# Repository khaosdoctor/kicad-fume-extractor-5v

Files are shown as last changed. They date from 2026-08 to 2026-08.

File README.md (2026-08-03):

# Fume Extractor 5V

KiCad project for a small, battery-powered fume extractor: a 9V battery feeds an
L7805 linear regulator to drive a 5V fan through a BC337 transistor, with a
potentiometer for speed control, a trimmer for calibration, a power switch and
an LED indicator.

This is my first electronics project, so it's a work in progress. Expect
multiple revisions as the design gets refined.

## PCB preview

| Top | Bottom |
|-----|---|
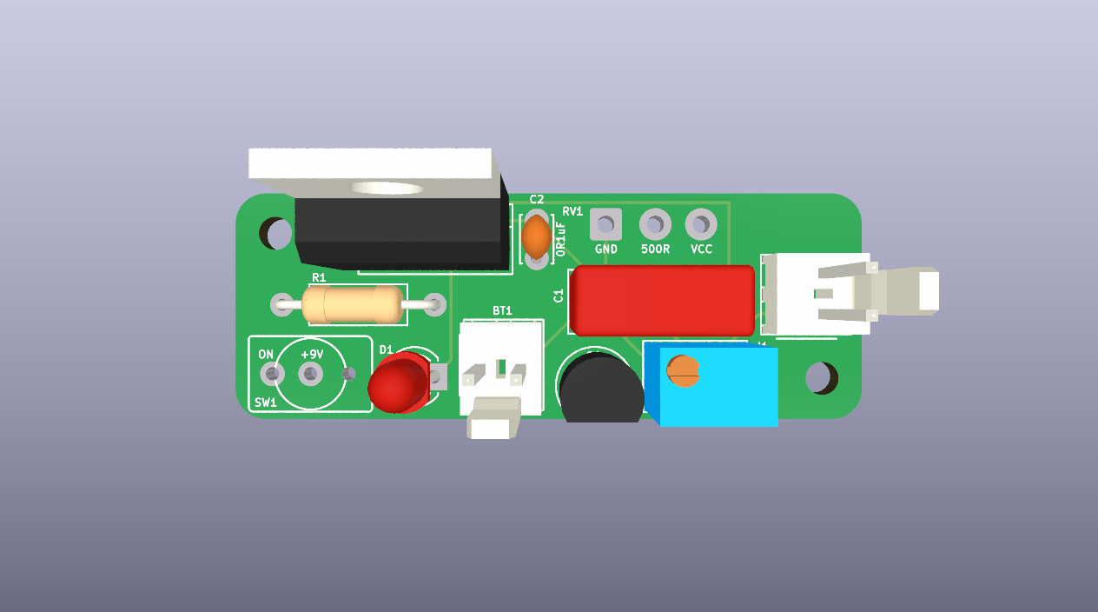
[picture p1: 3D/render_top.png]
PCB top view
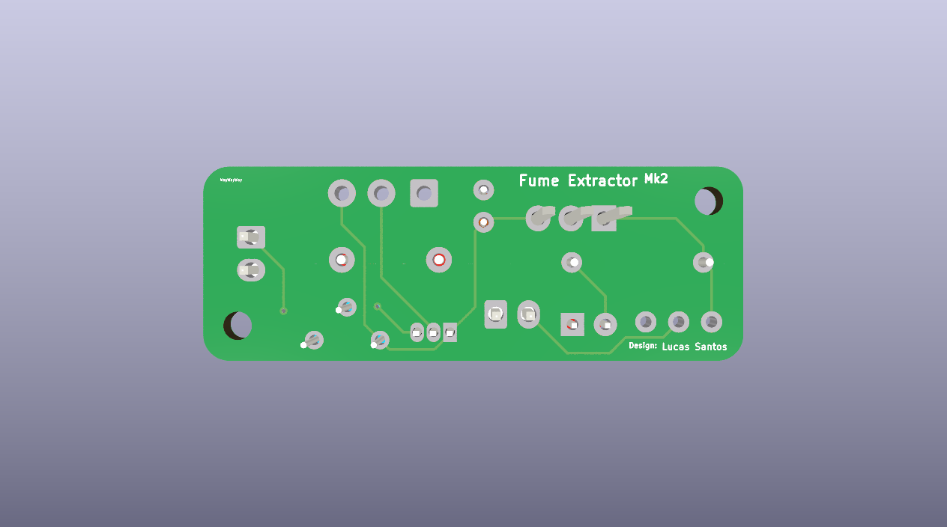
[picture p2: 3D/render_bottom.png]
PCB bottom view
|  |  |

## Hardware overview

Interactive BOM: [khaosdoctor.github.io/kicad-fume-extractor-5v/bom/ibom.html](https://khaosdoctor.github.io/kicad-fume-extractor-5v/bom/ibom.html)

| Ref  | Part | Function |
|---|---|---|
| BT1  | 9V battery cell | Power source |
| U1 | L7805ACV | 5V linear regulator |
| Q1 | BC337 | Fan drive transistor |
| J1 | 2-pin connector | Fan output |
| RV1  | 500R potentiometer | Fan speed control |
| RV2  | 1K trimmer | Calibration |
| R1 | 350R resistor | Bias/current limiting |
| C1/C2| Capacitors | Regulator input/output filtering  |
| D1 | LED | Power indicator |
| SW1  | SPST switch | Power on/off |

The board is a 2-layer PCB designed in KiCad 10.

## Generating manufacturing files with KiBot

This project uses [KiBot](https://github.com/INTI-CMNB/KiBot) to generate
gerbers, drill files, pick & place, BOM, documentation and 3D outputs
straight from the KiCad source files, via `kibot.yaml`.

### Outputs produced

| Group | Outputs | Directory |
|---|---|---|
| `fabrication` | Gerbers, Excellon drill files | `Manufacturing/Gerbers` |
| `assembly` | Pick & place position file, BOM (CSV) | `Manufacturing/Assembly`|
| `documentation` | Schematic PDF, PCB PDF, interactive HTML BOM | `Documentation`, `bom`  |
| `3d` | STEP model, top/bottom 3D renders | `3D` |

A zipped bundle of gerbers + drill files ready to send to a fab house is also
produced under `Manufacturing/manufacturing_zip.zip`. A JLCPCB-specific BOM
(`bom_jlcpcb`) filtered to parts with an LCSC part number is available but not
run by default.

### Running locally

Install KiCad (10.x) and KiBot, then from the repository root run:

```bash
pip install kibot
kibot -e "fume Extractor.kicad_sch" -b "fume Extractor.kicad_pcb"
```

To generate a single group or output, pass its name as a target, e.g.:

```bash
kibot -e "fume Extractor.kicad_sch" -b "fume Extractor.kicad_pcb" fabrication
```

### Running with Docker

No local KiCad/KiBot install is required if you have Docker:

```bash
docker run --rm -v "$(pwd)":/mnt ghcr.io/inti-cmnb/kicad10_auto_full:latest \
  kibot -e "fume Extractor.kicad_sch" -b "fume Extractor.kicad_pcb"
```

### Running in CI

The [`kibot.yml`](.github/workflows/kibot.yml) workflow runs KiBot on every
push and pull request and uploads the generated files as a build artifact.
On pushes to `main` it also commits the refreshed `bom/ibom.html`,
`3D/render_top.png` and `3D/render_bottom.png` back to the repo, which is
what keeps the PCB preview and interactive BOM link above up to date.

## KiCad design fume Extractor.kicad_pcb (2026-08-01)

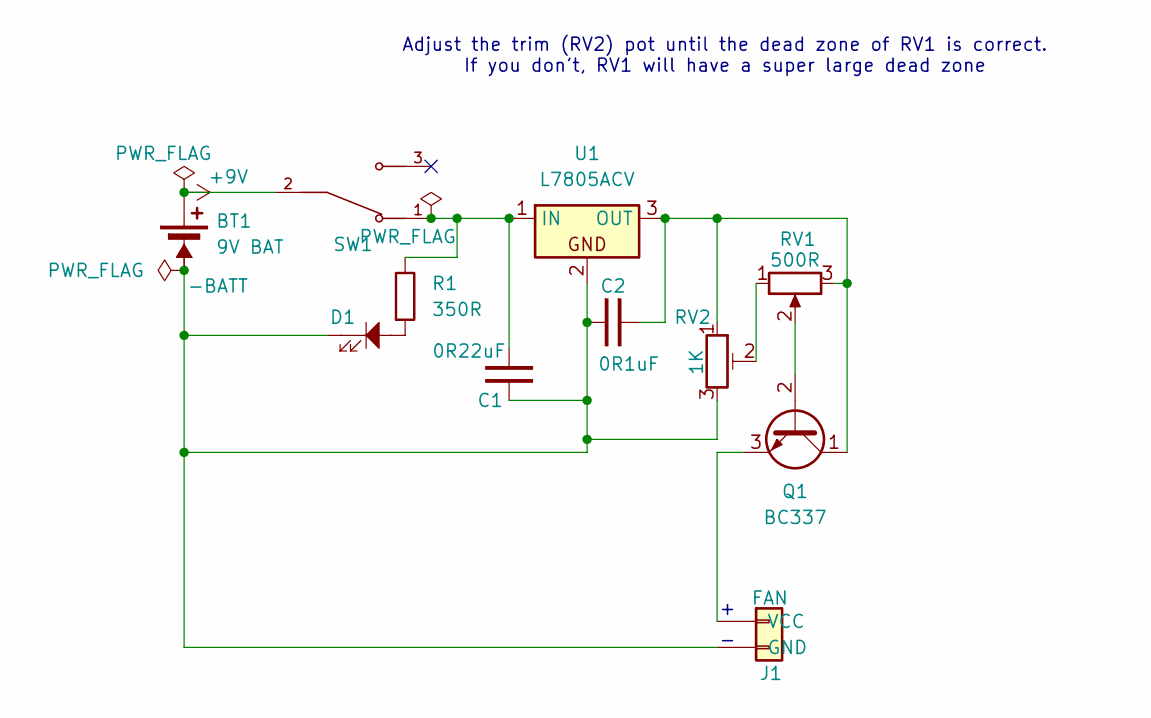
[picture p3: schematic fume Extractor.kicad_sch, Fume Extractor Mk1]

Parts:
BT1: 9V BAT; Molex_KK-254_AE-6410-02A_1x02_P2.54mm_Vertical
C1: 0R22uF; C_Rect_L10.0mm_W4.0mm_P7.50mm_MKS4
C2: 0R1uF; C_Disc_D3.0mm_W2.0mm_P2.50mm
D1: LED_3mm; LED_D3.0mm
J1: FAN; Molex_KK-254_AE-6410-02A_1x02_P2.54mm_Vertical
Q1: BC337; TO-92_Inline
R1: 350R; R_Axial_DIN0207_L6.3mm_D2.5mm_P10.16mm_Horizontal
RV1: 500R; SolderWire-0.5sqmm_1x03_P4.6mm_D0.9mm_OD2.1mm
RV2: 1K; Potentiometer_Bourns_3266W_Vertical
SW1: SW_SPST; Switch_Toggle_SPDT_SubMini; PARTREV E
U1: L7805ACV; TO-220-3_Vertical

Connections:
+9V: BT1.1 (+), SW1.2
-BATT: BT1.2 (-), C1.2, C2.1, D1.1, J1.2 (GND), RV2.3, U1.2
unnamed: D1.2, R1.1
unnamed: J1.1 (VCC), Q1.3 (E)
unnamed: Q1.2 (B), RV1.2
unnamed: C2.2, Q1.1 (C), RV1.3, RV2.1, U1.3 (OUT)
unnamed: RV1.1, RV2.2
unnamed: C1.1, R1.2, SW1.1, U1.1 (IN)

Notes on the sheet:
Adjust the trim (RV2) pot until the dead zone of RV1 is correct. If you don't, RV1 will have a super large dead zone

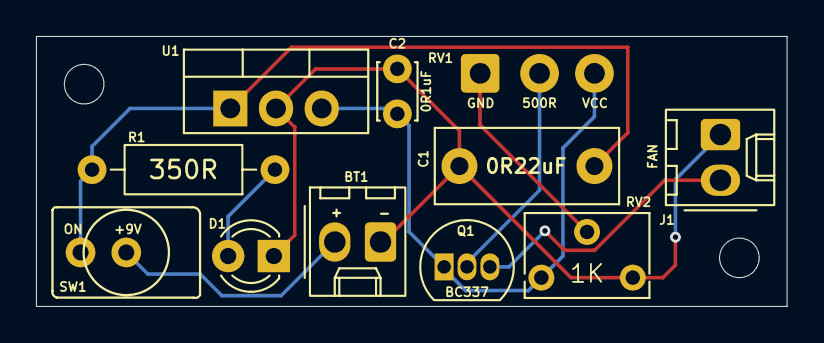
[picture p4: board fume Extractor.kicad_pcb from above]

Board: 2 copper layers, 41.7 x 15.0 mm, 11 parts (0 on the bottom side), 8 nets.

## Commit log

2026-07-09 feat: initial commit
    [fume Extractor.kicad_pcb, fume Extractor.kicad_sch]
2026-07-09 fix: adjust pp cap and sizes
    [fume Extractor.kicad_pcb, fume Extractor.kicad_sch]
2026-07-10 feat: v2 with trimmer pot
    Added RV2 to avoid long dead zones in RV1 because 500ohm is too much to
    limit the 2V needed to minimally drive the fan, so the pot is largelly
    dead. Adding a 1k 3266 Trimmer increases the ground resistance and the
    floor voltage so we need to turn RV1 less to start the fan.
    Plus, this gives a finer control over the fan speed itself
    [fume Extractor.kicad_pcb, fume Extractor.kicad_sch]
2026-07-10 feat: add BOM
2026-08-01 Add Version 2
    [fume Extractor.kicad_pcb, fume Extractor.kicad_sch]
2026-08-01 chore: update bom for v2
2026-08-03 Add KiBot config, CI workflow, and README
    Generates gerbers, drill, pick & place, BOM, PDFs, interactive HTML
    BOM, STEP and 3D renders from the KiCad source files, plus a GitHub
    Actions workflow that runs KiBot on push/PR.
2026-08-03 Auto-publish interactive BOM and PCB renders via CI
    Gives the renders stable filenames (3D/render_top.png,
    3D/render_bottom.png) so they can be embedded in the README, and has
    the CI workflow commit them plus bom/ibom.html back to main after
    every KiBot run so they stay in sync with the board. The interactive
    BOM is linked through GitHub Pages once enabled for the repo.
2026-08-03 Move interactive BOM link into hardware overview
    Drops the separate GitHub Pages setup note and the explanation that
    PCB renders come from CI, keeping the README focused on the project
    itself.
2026-08-03 chore: refresh interactive BOM and PCB renders [skip ci]
2026-08-03 Widen CI auto-commit pattern for bom/ to catch actual ibom filename
    Last run deleted bom/ibom.html without recreating it: KiBot and
    InteractiveHtmlBom's own source both compute that exact path from
    name_format 'ibom', so nothing found should explain the deletion, but
    the exact-path file_pattern in git-auto-commit-action means if the
    real generated file has a different name, git sees the tracked path
    as removed and stages the deletion silently. Matching bom/* instead
    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
2026-08-03 Fix interactive BOM filename
    IBoMOptions.output defaults to KiBot's global naming pattern
    (%f-%i%I%v.%x), not empty, so it was expanding to
    "fume Extractor-ibom.html" regardless of the name_format option,
    which only applies when output is unset. Setting output explicitly
    to 'ibom.html' gives a stable path for the README link and GitHub
    Pages, independent of the PCB's title text.
    Removes the wrongly-named file CI committed; the next run will
    regenerate bom/ibom.html in its place.
